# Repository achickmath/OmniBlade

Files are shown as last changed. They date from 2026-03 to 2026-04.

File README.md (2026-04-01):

# OmniBlade

A motion-based adaptive game controller for players with limb differences. Strap it to your arms, tilt to move, flick to attack. No buttons. No joysticks. Just motion.

---

## The Idea

Most adaptive controllers are expensive, limited, or designed as an afterthought. OmniBlade is built from scratch around a simple idea — if someone has an arm, they can play. Two IMU sensors read the motion of each arm in real time and map it to a full Xbox controller input. Voice handles the rest.

---

## Hardware

- 2x ESP32 DEVKIT V1 (CP2102, USB-C)
- 2x MPU-6050 6-axis IMU
- 2x Half-size breadboard
- Jumper wires
- 3D printed forearm housing (3MF files in `/housing`)
- Velcro straps

## Wiring (each unit)

| MPU-6050 | ESP32 |
|---|---|
| VCC | 3.3V |
| GND | GND |
| SDA | GPIO21 |
| SCL | GPIO22 |

---

## How It Works

Each ESP32 reads accelerometer and gyroscope data from its MPU-6050 over I2C at 50Hz. A complementary filter fuses the two signals into stable roll and pitch angles. Gyroscope spikes above a threshold are classified as flick gestures. All of this streams over USB serial to a Python script that maps the data to a virtual Xbox controller using vgamepad.

Voice commands are handled separately by VoiceAttack, which sends F-key presses that the script listens for via pynput.

---

## Setup

Flash `main.cpp` to both ESP32s using PlatformIO or Arduino IDE. Then install Python dependencies:

```
pip install pyserial vgamepad pynput
```

Find your COM ports:

```
[System.IO.Ports.SerialPort]::GetPortNames()
```

Update `LEFT_PORT` and `RIGHT_PORT` in the script, then run:

```
python dual_imu.py
```

Hold both arms neutral for 3 seconds on startup for calibration.

---

## Scripts

- `dual_imu.py` — universal script, works for any game
- `dual_forza.py` — Forza specific, analog throttle and brake on right arm tilt

---

## Button Mapping

**Left arm** — tilt for left stick, flicks for X / LT / Y / LB

**Right arm** — tilt for right stick, flicks for RT / A / B / RB

**Voice** — Start, Select, D-pad, L3, R3 via VoiceAttack

Full mapping in the user guide.

---

## Known Issues

- Hold arms neutral on startup or calibration will be off
- Some power banks auto-shutoff at low current draw
- vgamepad requires the correct Python environment on Windows

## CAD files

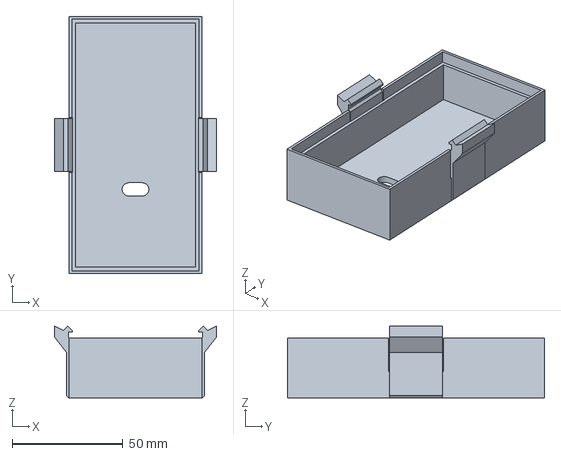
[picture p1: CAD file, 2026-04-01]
housing/BoxTop.3mf
73.0 x 116.0 x 32.4 mm

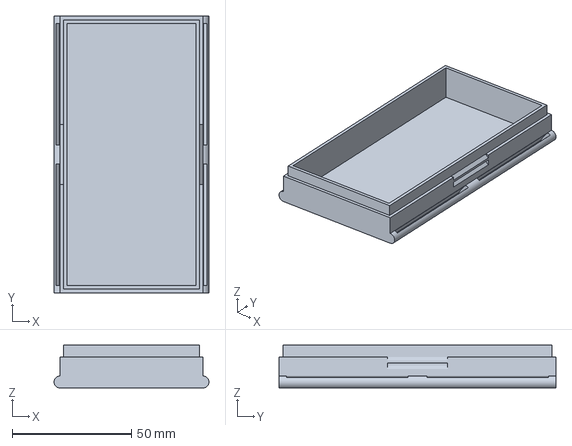
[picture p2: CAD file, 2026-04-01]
housing/BoxBottom.3mf
65.0 x 116.0 x 18.0 mm

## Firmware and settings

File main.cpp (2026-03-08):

#include <Arduino.h>
#include <Adafruit_MPU6050.h>
#include <Adafruit_Sensor.h>
#include <Wire.h>
#include <BluetoothSerial.h>

BluetoothSerial SerialBT;
Adafruit_MPU6050 mpu;

float roll = 0, pitch = 0;
unsigned long lastTime = 0;
const float ALPHA = 0.96;

float roll_offset = 0, pitch_offset = 0;
bool calibrated = false;
int cal_count = 0;
float cal_roll_sum = 0, cal_pitch_sum = 0;
const int CAL_SAMPLES = 150;

const float FLICK_THRESHOLD = 600.0;
const unsigned long FLICK_COOLDOWN = 250;
unsigned long last_flick_time = 0;

String detectFlick(float gx, float gy) {
  unsigned long now = millis();
  if (now - last_flick_time < FLICK_COOLDOWN) return "";

  if (gy > FLICK_THRESHOLD)  { last_flick_time = now; return "FLICK_FORWARD"; }
  if (gy < -FLICK_THRESHOLD) { last_flick_time = now; return "FLICK_BACK"; }
  if (gx > FLICK_THRESHOLD)  { last_flick_time = now; return "FLICK_RIGHT"; }
  if (gx < -FLICK_THRESHOLD) { last_flick_time = now; return "FLICK_LEFT"; }

  return "";
}

void setup() {
  Serial.begin(115200);
  SerialBT.begin("OmniController");
  Wire.begin(21, 22);
  delay(1000);

  if (!mpu.begin()) {
    Serial.println("MPU6050 not found!");
    while (1) delay(10);
  }

  mpu.setAccelerometerRange(MPU6050_RANGE_4_G);
  mpu.setGyroRange(MPU6050_RANGE_2000_DEG);
  mpu.setFilterBandwidth(MPU6050_BAND_21_HZ);

  lastTime = millis();
  Serial.println("READY - Hold neutral position for calibration...");
}

void loop() {
  sensors_event_t a, g, temp;
  mpu.getEvent(&a, &g, &temp);

  unsigned long now = millis();
  float dt = (now - lastTime) / 1000.0;
  lastTime = now;

  float accelRoll  = atan2(a.acceleration.y, a.acceleration.z) * 180.0 / PI;
  float accelPitch = atan2(-a.acceleration.x, sqrt(a.acceleration.y * a.acceleration.y + a.acceleration.z * a.acceleration.z)) * 180.0 / PI;

  float gyroRollRate  = g.gyro.x * 180.0 / PI;
  float gyroPitchRate = g.gyro.y * 180.0 / PI;

  roll  = ALPHA * (roll  + gyroRollRate  * dt) + (1 - ALPHA) * accelRoll;
  pitch = ALPHA * (pitch + gyroPitchRate * dt) + (1 - ALPHA) * accelPitch;

  if (!calibrated) {
    cal_roll_sum  += roll;
    cal_pitch_sum += pitch;
    cal_count++;

    if (cal_count >= CAL_SAMPLES) {
      roll_offset  = cal_roll_sum  / CAL_SAMPLES;
      pitch_offset = cal_pitch_sum / CAL_SAMPLES;
      calibrated = true;
      Serial.println("Calibration done.");
      SerialBT.println("Calibration done.");
    }
    return;
  }

  float cal_roll  = roll  - roll_offset;
  float cal_pitch = pitch - pitch_offset;

  float gx_deg = g.gyro.x * 180.0 / PI;
  float gy_deg = g.gyro.y * 180.0 / PI;
  float gz_deg = g.gyro.z * 180.0 / PI;

  String flick = detectFlick(gx_deg, gy_deg);

  String data = String(a.acceleration.x, 3) + "," +
                String(a.acceleration.y, 3) + "," +
                String(a.acceleration.z, 3) + "," +
                String(gx_deg, 3) + "," +
                String(gy_deg, 3) + "," +
                String(gz_deg, 3) + "," +
                String(cal_roll, 3) + "," +
                String(cal_pitch, 3) + "," +
                String(0.0, 3) + "," +
                flick;

  Serial.println(data);
  SerialBT.println(data);

  delay(20);
}

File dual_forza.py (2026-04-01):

import serial
import time
import threading
import vgamepad as vg
from pynput import keyboard

# --- Config ---
LEFT_PORT  = "COM6"
RIGHT_PORT = "COM9"
BAUD = 115200

LEFT_DEADZONE = 5.0
LEFT_MAX = 20.0
RIGHT_DEADZONE = 10.0
RIGHT_MAX = 40.0

gamepad = vg.VX360Gamepad()

def on_press(key):
    try:
        if key == keyboard.Key.f13:
            gamepad.press_button(button=vg.XUSB_BUTTON.XUSB_GAMEPAD_START)
            gamepad.update()
            time.sleep(0.05)
            gamepad.release_button(button=vg.XUSB_BUTTON.XUSB_GAMEPAD_START)
            gamepad.update()
            print("*** START ***")
        elif key == keyboard.Key.f14:
            gamepad.press_button(button=vg.XUSB_BUTTON.XUSB_GAMEPAD_BACK)
            gamepad.update()
            time.sleep(0.05)
            gamepad.release_button(button=vg.XUSB_BUTTON.XUSB_GAMEPAD_BACK)
            gamepad.update()
            print("*** SELECT ***")
        elif key == keyboard.Key.f15:
            gamepad.press_button(button=vg.XUSB_BUTTON.XUSB_GAMEPAD_DPAD_UP)
            gamepad.update()
            time.sleep(0.05)
            gamepad.release_button(button=vg.XUSB_BUTTON.XUSB_GAMEPAD_DPAD_UP)
            gamepad.update()
        elif key == keyboard.Key.f16:
            gamepad.press_button(button=vg.XUSB_BUTTON.XUSB_GAMEPAD_DPAD_DOWN)
            gamepad.update()
            time.sleep(0.05)
            gamepad.release_button(button=vg.XUSB_BUTTON.XUSB_GAMEPAD_DPAD_DOWN)
            gamepad.update()
        elif key == keyboard.Key.f17:
            gamepad.press_button(button=vg.XUSB_BUTTON.XUSB_GAMEPAD_DPAD_LEFT)
            gamepad.update()
            time.sleep(0.05)
            gamepad.release_button(button=vg.XUSB_BUTTON.XUSB_GAMEPAD_DPAD_LEFT)
            gamepad.update()
        elif key == keyboard.Key.f18:
            gamepad.press_button(button=vg.XUSB_BUTTON.XUSB_GAMEPAD_DPAD_RIGHT)
            gamepad.update()
            time.sleep(0.05)
            gamepad.release_button(button=vg.XUSB_BUTTON.XUSB_GAMEPAD_DPAD_RIGHT)
            gamepad.update()
    except Exception as e:
        print(f"Key error: {e}")

listener = keyboard.Listener(on_press=on_press)
listener.start()

def normalize(val, deadzone, max_angle):
    if abs(val) < deadzone:
        return 0.0
    sign = 1.0 if val > 0 else -1.0
    normalized = (abs(val) - deadzone) / (max_angle - deadzone)
    return max(-1.0, min(1.0, sign * normalized))

def normalize_trigger(val, deadzone, max_angle):
    if val < deadzone:
        return 0
    normalized = (val - deadzone) / (max_angle - deadzone)
    return int(min(1.0, normalized) * 255)

def parse_line(line):
    try:
        val = line.split(",")
        if len(val) == 10:
            roll  = float(val[7])
            pitch = float(val[6])
            flick = val[9].strip()
            return roll, pitch, flick
    except:
        pass
    return None, None, None

def handle_flick_left(flick):
    if flick == "FLICK_FORWARD":
        gamepad.press_button(button=vg.XUSB_BUTTON.XUSB_GAMEPAD_A)
        gamepad.update()
        time.sleep(0.05)
        gamepad.release_button(button=vg.XUSB_BUTTON.XUSB_GAMEPAD_A)
        gamepad.update()
        print("*** A (rewind) ***")
    elif flick == "FLICK_BACK":
        gamepad.press_button(button=vg.XUSB_BUTTON.XUSB_GAMEPAD_X)
        gamepad.update()
        time.sleep(0.05)
        gamepad.release_button(button=vg.XUSB_BUTTON.XUSB_GAMEPAD_X)
        gamepad.update()
        print("*** X ***")
    elif flick == "FLICK_LEFT":
        gamepad.press_button(button=vg.XUSB_BUTTON.XUSB_GAMEPAD_Y)
        gamepad.update()
        time.sleep(0.05)
        gamepad.release_button(button=vg.XUSB_BUTTON.XUSB_GAMEPAD_Y)
        gamepad.update()
        print("*** Y ***")
    elif flick == "FLICK_RIGHT":
        gamepad.press_button(button=vg.XUSB_BUTTON.XUSB_GAMEPAD_B)
        gamepad.update()
        time.sleep(0.05)
        gamepad.release_button(button=vg.XUSB_BUTTON.XUSB_GAMEPAD_B)
        gamepad.update()
        print("*** B ***")

def handle_flick_right(flick):
    if flick == "FLICK_FORWARD":
        gamepad.press_button(button=vg.XUSB_BUTTON.XUSB_GAMEPAD_RIGHT_SHOULDER)
        gamepad.update()
        time.sleep(0.05)
        gamepad.release_button(button=vg.XUSB_BUTTON.XUSB_GAMEPAD_RIGHT_SHOULDER)
        gamepad.update()
        print("*** RB ***")
    elif flick == "FLICK_BACK":
        gamepad.press_button(button=vg.XUSB_BUTTON.XUSB_GAMEPAD_LEFT_SHOULDER)
        gamepad.update()
        time.sleep(0.05)
        gamepad.release_button(button=vg.XUSB_BUTTON.XUSB_GAMEPAD_LEFT_SHOULDER)
        gamepad.update()
        print("*** LB ***")

def left_arm_loop():
    port = serial.Serial(LEFT_PORT, BAUD, timeout=1)
    time.sleep(3)
    print("Left arm connected.")
    while True:
        if port.in_waiting > 0:
            try:
                line = port.readline().decode('utf-8').strip()
                if not line or "," not in line:
                    continue
                roll, pitch, flick = parse_line(line)
                if roll is None:
                    continue

                # Steering — left stick X only
                lx = normalize(pitch, LEFT_DEADZONE, LEFT_MAX)
                gamepad.left_joystick_float(x_value_float=lx, y_value_float=0.0)
                gamepad.update()

                if flick:
                    handle_flick_left(flick)
            except Exception as e:
                print(f"Left arm error: {e}")

def right_arm_loop():
    port = serial.Serial(RIGHT_PORT, BAUD, timeout=1)
    time.sleep(3)
    print("Right arm connected.")
    while True:
        if port.in_waiting > 0:
            try:
                line = port.readline().decode('utf-8').strip()
                if not line or "," not in line:
                    continue
                roll, pitch, flick = parse_line(line)
                if roll is None:
                    continue

                # Roll forward = throttle (RT), roll back = brake (LT)
                if roll > RIGHT_DEADZONE:
                    rt = normalize_trigger(roll, RIGHT_DEADZONE, RIGHT_MAX)
                    gamepad.right_trigger(value=rt)
                    gamepad.left_trigger(value=0)
                elif roll < -RIGHT_DEADZONE:
                    lt = normalize_trigger(-roll, RIGHT_DEADZONE, RIGHT_MAX)
                    gamepad.left_trigger(value=lt)
                    gamepad.right_trigger(value=0)
                else:
                    gamepad.right_trigger(value=0)
                    gamepad.left_trigger(value=0)
                gamepad.update()

                if flick:
                    handle_flick_right(flick)
            except Exception as e:
                print(f"Right arm error: {e}")

t1 = threading.Thread(target=left_arm_loop, daemon=True)
t2 = threading.Thread(target=right_arm_loop, daemon=True)
t1.start()
t2.start()
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
